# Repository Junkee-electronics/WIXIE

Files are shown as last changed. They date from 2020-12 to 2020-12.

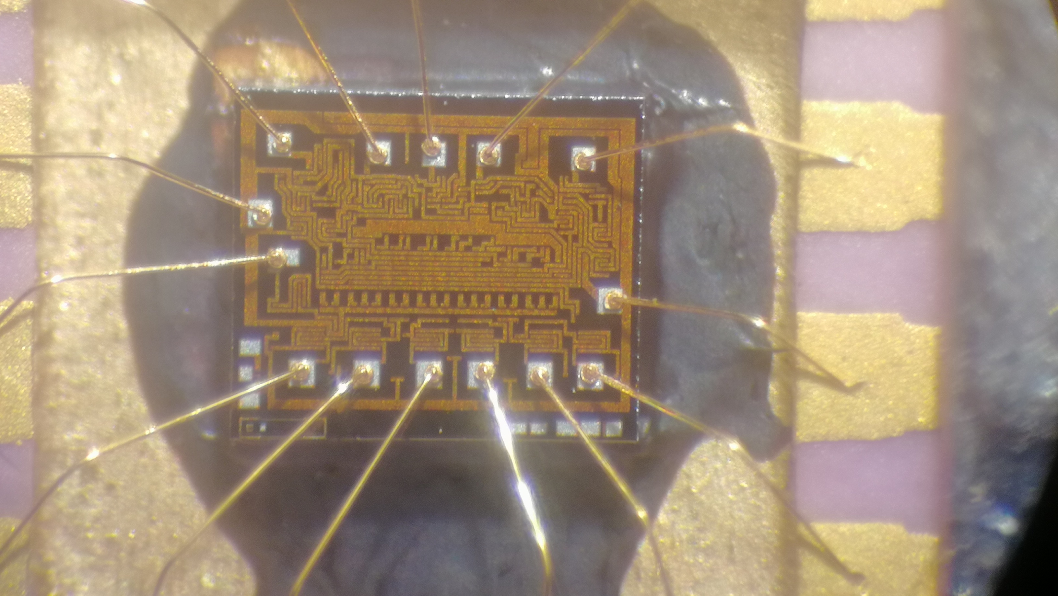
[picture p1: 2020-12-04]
k133ID1.jpg

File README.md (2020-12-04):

# WIXIE

a project for 2 digit nixie watch.
single button operation etc.
synchronised via RTC.
wireless charging.

//No alarms yet! (maybe in the future)
EDIT: ok, i thought about it and i think i implemented it somewhat okay.

possibly will be developing the PCB in the near future.

currently moved to a backburner, as it tested ok, but the driver chip for the nixies is KO.

if anyone is curious, ill upload the supposed k133ID1 delidded picture. by my assumption, its mighty suss.
  -of outer 16 pins, internally bonded only 14.
  -outer VCC pin isn't connected to anything, not even the base platform for the substrate (not even bonded directly to the platform, only glued).
  -lacking amount of output buffer transistors, i count only 7.
well, what could i expect from russians, huh (an attemted joke) :)

STILL DISLIKE LIBRARIES;

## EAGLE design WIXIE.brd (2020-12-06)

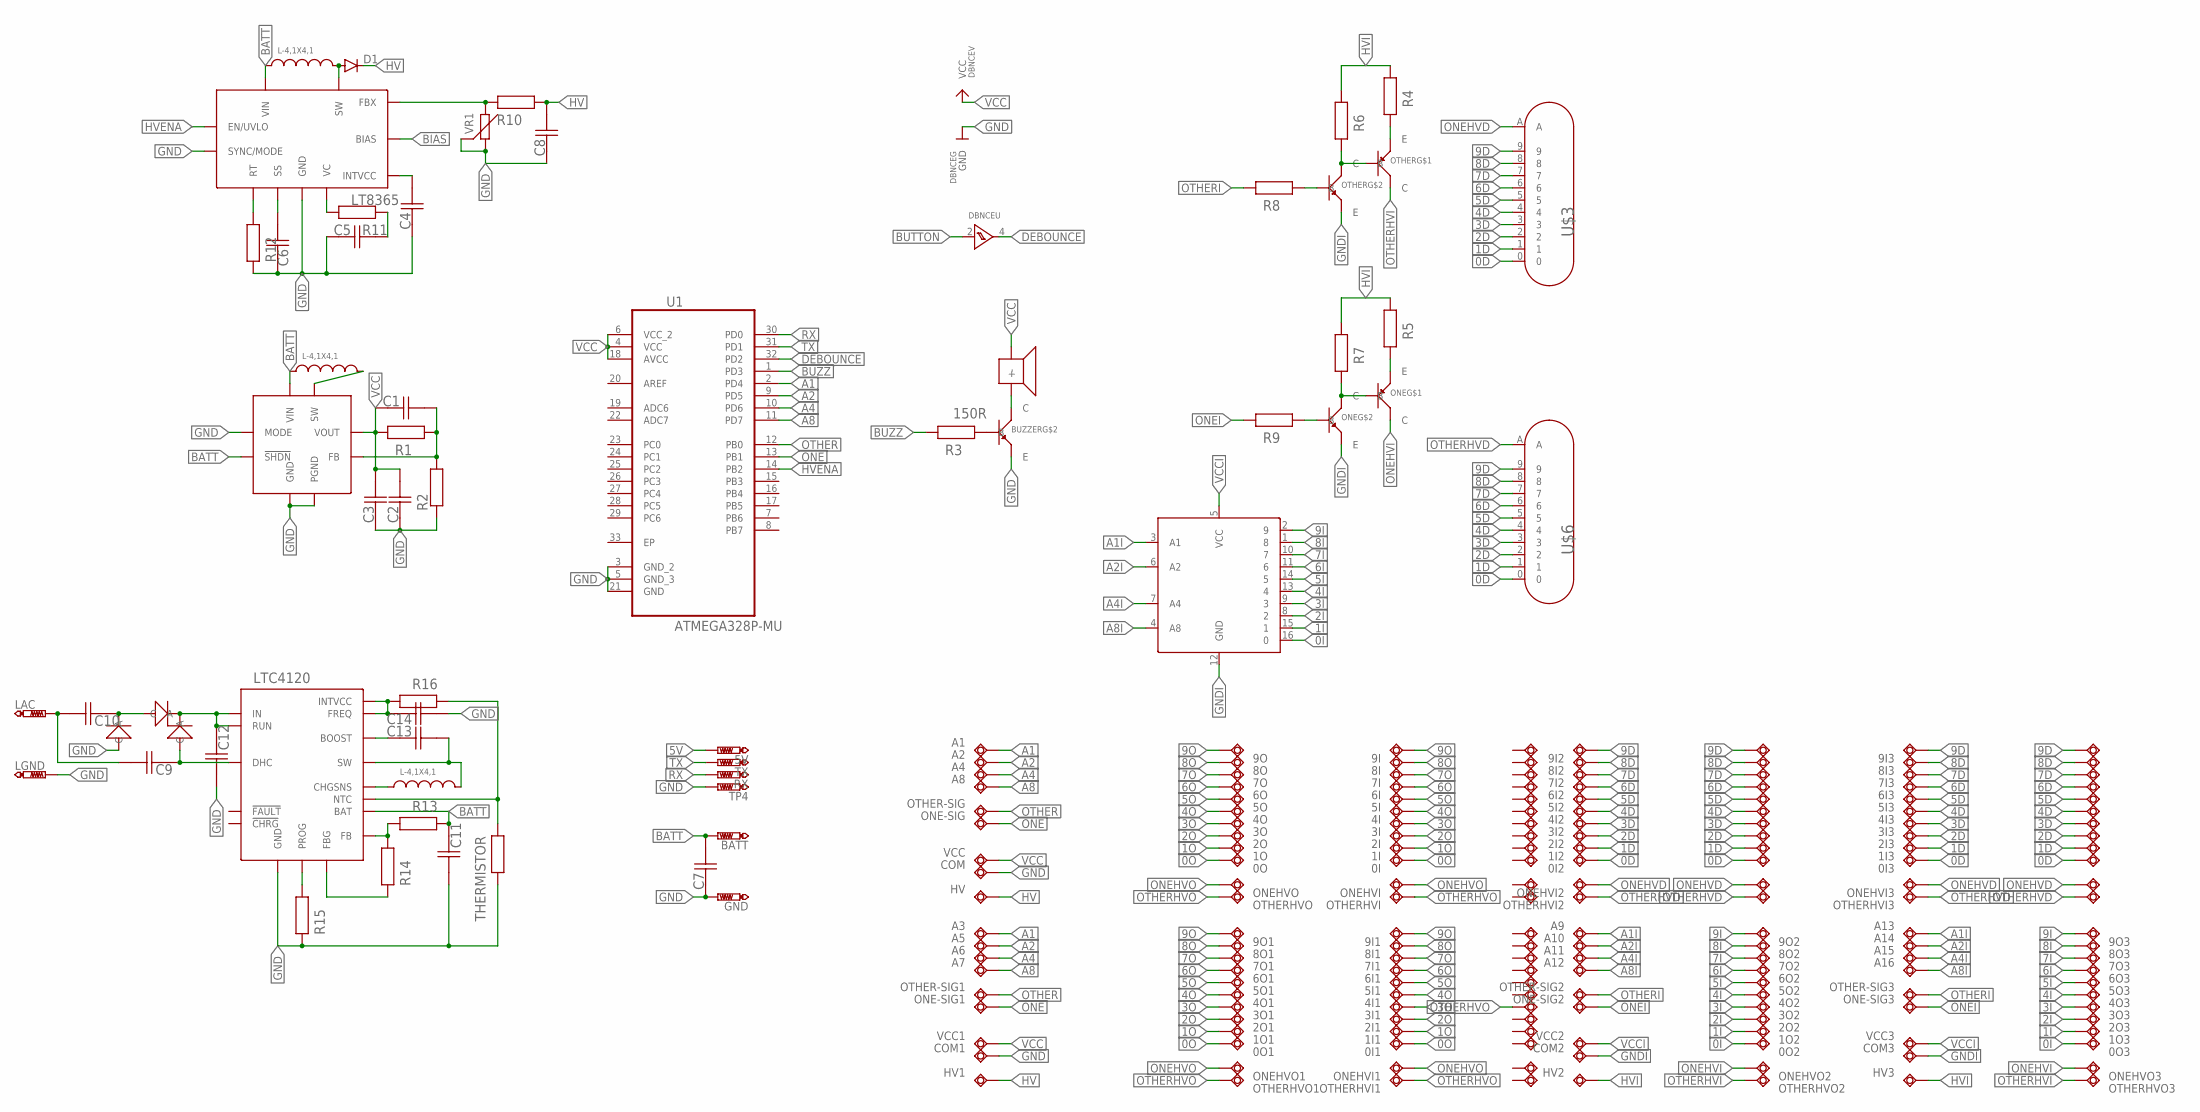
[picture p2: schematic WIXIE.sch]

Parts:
0I, 0I1, 0I2, 0I3, 0O, 0O1, 0O2, 0O3, 1I, 1I1, 1I2, 1I3, 1O, 1O1, 1O2, 1O3, 2I, 2I1, 2I2, 2I3, 2O, 2O1, 2O2, 2O3, 3I, 3I1, 3I2, 3I3, 3O, 3O1, 3O2, 3O3, 4I, 4I1, 4I2, 4I3, 4O, 4O1, 4O2, 4O3, 5I, 5I1, 5I2, 5I3, 5O, 5O1, 5O2, 5O3, 6I, 6I1, 6I2, 6I3, 6O, 6O1, 6O2, 6O3, 7I, 7I1, 7I2, 7I3, 7O, 7O1, 7O2, 7O3, 8I, 8I1, 8I2, 8I3, 8O, 8O1, 8O2, 8O3, 9I, 9I1, 9I2, 9I3, 9O, 9O1, 9O2, 9O3: TPSQTP12SQ; TP12SQ
5V: PTR1B1,27; B1,27
A1, A2, A3, A4, A5, A6, A7, A8, A9, A10, A11, A12, A13, A14, A15, A16: TPSQTP12SQ; TP12SQ
BATT: PTR1PAD1-13; P1-13
BUZZER: MMDT5451; SOT-363
C1, C2, C3, C4, C5, C6, C7, C8, C9, C10, C11, C12, C13, C14: CAPACITOR-0603; 0603
COM, COM1, COM2, COM3: TPSQTP12SQ; TP12SQ
D1: DIODE-SOD123; SOD123
DBNCE: 74AHC1G17; SOT-353-1
GND: PTR1PAD1-13; P1-13
HV, HV1, HV2, HV3: TPSQTP12SQ; TP12SQ
LAC: PTR1PAD1-13; P1-13
LGND: PTR1PAD1-13; P1-13
LT8365: LT8365; MSE16
LTC3539: LTC3539; DFN8-2X3
LTC4120: LTC4120; QFN16
ONE: MMDT5451; SOT-363
ONE-SIG, ONE-SIG1, ONE-SIG2, ONE-SIG3: TPSQTP12SQ; TP12SQ
ONEHVI, ONEHVI1, ONEHVI2, ONEHVI3: TPSQTP12SQ; TP12SQ
ONEHVO, ONEHVO1, ONEHVO2, ONEHVO3: TPSQTP12SQ; TP12SQ
OTHER: MMDT5451; SOT-363
OTHER-SIG, OTHER-SIG1, OTHER-SIG2, OTHER-SIG3: TPSQTP12SQ; TP12SQ
OTHERHVI, OTHERHVI1, OTHERHVI2, OTHERHVI3: TPSQTP12SQ; TP12SQ
OTHERHVO, OTHERHVO1, OTHERHVO2, OTHERHVO3: TPSQTP12SQ; TP12SQ
R1, R2, R4, R5, R6, R7, R8, R9, R10, R11, R12, R13, R14, R15, R16: RESISTOR-0603; 0603
R3: 150R; 0603
RX: PTR1B1,27; B1,27
THERMISTOR: RESISTOR-0603; 0603
TP1, TP2, TP3, TP5, TP6, TP7, TP8, TP9, TP10, TP11, TP12, TP13, TP14, TP15, TP16, TP17, TP18, TP19, TP20, TP21, TP22, TP23, TP24, TP25, TP26, TP27, TP28, TP29, TP30, TP31, TP32, TP33, TP34, TP35, TP36, TP37, TP38, TP39, TP40, TP41, TP42, TP43, TP44, TP45, TP46, TP47, TP48, TP49: TPSQTP12SQ; TP12SQ
TP4: PTR1B1,27; B1,27
TX: PTR1B1,27; B1,27
U1: ATMEGA328P-MU; QFN50P500X500X100-33N
U$2: BUZZ-8.5X8.5
U$3, U$6: IN-17
U$5, U$11, U$12: ZENER0603; 0603DIODE
U$7, U$8, U$10: L-4,1X4,1; L-4.1X4.1
U$9: K133ID1
VCC, VCC1, VCC2, VCC3: TPSQTP12SQ; TP12SQ
VR1: SR3305

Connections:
0D: 0I2.TP, 0I3.TP, TP23.TP, TP47.TP, U$3.0, U$6.0
0I: 0O2.TP, 0O3.TP, U$9.16 (0)
0O: 0I.TP, 0I1.TP, 0O.TP, 0O1.TP
1D: 1I2.TP, 1I3.TP, TP22.TP, TP34.TP, U$3.1, U$6.1
1I: 1O2.TP, 1O3.TP, U$9.15 (1)
1O: 1I.TP, 1I1.TP, 1O.TP, 1O1.TP
2D: 2I2.TP, 2I3.TP, TP21.TP, TP33.TP, U$3.2, U$6.2
2I: 2O2.TP, 2O3.TP, U$9.8 (2)
2O: 2I.TP, 2I1.TP, 2O.TP, 2O1.TP
3D: 3I2.TP, 3I3.TP, TP20.TP, TP32.TP, U$3.3, U$6.3
3I: 3O2.TP, 3O3.TP, U$9.9 (3)
3O: 3I.TP, 3I1.TP, 3O.TP, 3O1.TP
4D: 4I2.TP, 4I3.TP, TP19.TP, TP31.TP, U$3.4, U$6.4
4I: 4O2.TP, 4O3.TP, U$9.13 (4)
4O: 4I.TP, 4I1.TP, 4O.TP, 4O1.TP
5D: 5I2.TP, 5I3.TP, TP18.TP, TP30.TP, U$3.5, U$6.5
5I: 5O2.TP, 5O3.TP, U$9.14 (5)
5O: 5I.TP, 5I1.TP, 5O.TP, 5O1.TP
5V: 5V.TP
6D: 6I2.TP, 6I3.TP, TP17.TP, TP29.TP, U$3.6, U$6.6
6I: 6O2.TP, 6O3.TP, U$9.11 (6)
6O: 6I.TP, 6I1.TP, 6O.TP, 6O1.TP
7D: 7I2.TP, 7I3.TP, TP16.TP, TP28.TP, U$3.7, U$6.7
7I: 7O2.TP, 7O3.TP, U$9.10 (7)
7O: 7I.TP, 7I1.TP, 7O.TP, 7O1.TP
8D: 8I2.TP, 8I3.TP, TP15.TP, TP27.TP, U$3.8, U$6.8
8I: 8O2.TP, 8O3.TP, U$9.1 (8)
8O: 8I.TP, 8I1.TP, 8O.TP, 8O1.TP
9D: 9I2.TP, 9I3.TP, TP14.TP, TP26.TP, U$3.9, U$6.9
9I: 9O2.TP, 9O3.TP, U$9.2 (9)
9O: 9I.TP, 9I1.TP, 9O.TP, 9O1.TP
A1: A1.TP, A3.TP, U1.2 (PD4)
A1I: A9.TP, A13.TP, U$9.3 (A1)
A2: A2.TP, A5.TP, U1.9 (PD5)
A2I: A10.TP, A14.TP, U$9.6 (A2)
A4: A4.TP, A6.TP, U1.10 (PD6)
A4I: A11.TP, A15.TP, U$9.7 (A4)
A8: A7.TP, A8.TP, U1.11 (PD7)
A8I: A12.TP, A16.TP, U$9.4 (A8)
BATT: BATT.TP, C7.2, C11.1, LT8365.3 (VIN), LTC3539.4 (VIN), LTC3539.5 (!SHDN), LTC4120.09 (BAT), R13.1, U$8.P$1, U$10.P$1
BIAS: LT8365.7 (BIAS)
BUTTON: DBNCE.2 (A)
BUZZ: R3.1, U1.1 (PD3)
DEBOUNCE: DBNCE.4 (Y), U1.32 (PD2)
GND: BUZZER.1 (E), C2.1, C3.1, C4.1, C5.1, C6.1, C7.1, C8.1, C11.2, C12.2, C14.2, COM.TP, COM1.TP, DBNCE.3 (GND), GND.TP, LGND.TP, LT8365.12 (SYNC/MODE), LT8365.PAD (GND), LTC3539.2 (PGND), LTC3539.3 (GND), LTC3539.7 (MODE), LTC3539.PAD (GND), LTC4120.05 (GND), R2.1, R12.1, R15.1, THERMISTOR.2, TP4.TP, U1.3 (GND_2), U1.5 (GND_3), U1.21 (GND), U$12.POS (A), VR1.2, VR1.3
GNDI: COM2.TP, COM3.TP, ONE.1 (E), OTHER.1 (E), U$9.12 (GND)
HV: C8.2, D1.C, HV.TP, HV1.TP, R10.2
HVENA: LT8365.1 (EN/UVLO), U1.14 (PB2)
HVI: HV2.TP, HV3.TP, R4.2, R5.2, R6.2, R7.2
N22: C1.2, LTC3539.6 (FB), R1.2, R2.2
unnamed: BUZZER.6 (C), U$2.-
unnamed: LTC3539.1 (SW), U$10.P$2
unnamed: OTHER.4 (E), R4.1
unnamed: BUZZER.2 (B), R3.2
unnamed: C4.2, LT8365.5 (INTVCC)
unnamed: OTHER.5 (B), OTHER.6 (C), R6.1
unnamed: C5.2, R11.2
unnamed: OTHER.2 (B), R8.2
unnamed: D1.A, LT8365.14 (SW), LT8365.16 (SW), U$8.P$2
unnamed: LT8365.9 (FBX), R10.1, VR1.1
unnamed: C10.1, U$5.POS (A), U$12.NEG (C)
unnamed: C9.2, C10.2, LAC.TP
unnamed: LT8365.8 (VC), R11.1
unnamed: C6.2, LT8365.11 (SS)
unnamed: LT8365.10 (RT), R12.2
unnamed: C12.1, LTC4120.03 (IN), LTC4120.16 (RUN), U$5.NEG (C), U$11.NEG (C)
unnamed: C9.1, LTC4120.06 (DHC), U$11.POS (A)
unnamed: LTC4120.13 (PROG), R15.2
unnamed: LTC4120.11 (FBG), R14.1
unnamed: LTC4120.10 (FB), R13.2, R14.2
unnamed: LTC4120.12 (NTC), R16.1, THERMISTOR.1
unnamed: LTC4120.08 (CHGSNS), U$7.P$1
unnamed: C13.2, LTC4120.04 (SW), U$7.P$2
unnamed: C13.1, LTC4120.02 (BOOST)
unnamed: C14.1, LTC4120.01 (INTVCC), LTC4120.07 (FREQ), R16.2
unnamed: ONE.2 (B), R9.2
unnamed: ONE.4 (E), R5.1
unnamed: ONE.5 (B), ONE.6 (C), R7.1
ONE: ONE-SIG.TP, ONE-SIG1.TP, U1.13 (PB1)
ONEHVD: ONEHVI2.TP, ONEHVI3.TP, TP24.TP, TP48.TP, U$3.A
ONEHVI: ONE.3 (C), ONEHVO2.TP, ONEHVO3.TP
ONEHVO: ONEHVI.TP, ONEHVI1.TP, ONEHVO.TP, ONEHVO1.TP
ONEI: ONE-SIG2.TP, ONE-SIG3.TP, R9.1
OTHER: OTHER-SIG.TP, OTHER-SIG1.TP, U1.12 (PB0)
OTHERHVD: OTHERHVI2.TP, OTHERHVI3.TP, TP25.TP, TP49.TP, U$6.A
OTHERHVI: OTHER.3 (C), OTHERHVO2.TP, OTHERHVO3.TP
OTHERHVO: OTHERHVI.TP, OTHERHVI1.TP, OTHERHVO.TP, OTHERHVO1.TP, TP8.TP
OTHERI: OTHER-SIG2.TP, OTHER-SIG3.TP, R8.1
RX: RX.TP, U1.30 (PD0)
TX: TX.TP, U1.31 (PD1)
VCC: C1.1, C2.2, C3.2, DBNCE.5 (VCC), LTC3539.8 (VOUT), R1.1, U1.4 (VCC), U1.6 (VCC_2), U1.18 (AVCC), U$2.+, VCC.TP, VCC1.TP
VCCI: U$9.5 (VCC), VCC2.TP, VCC3.TP

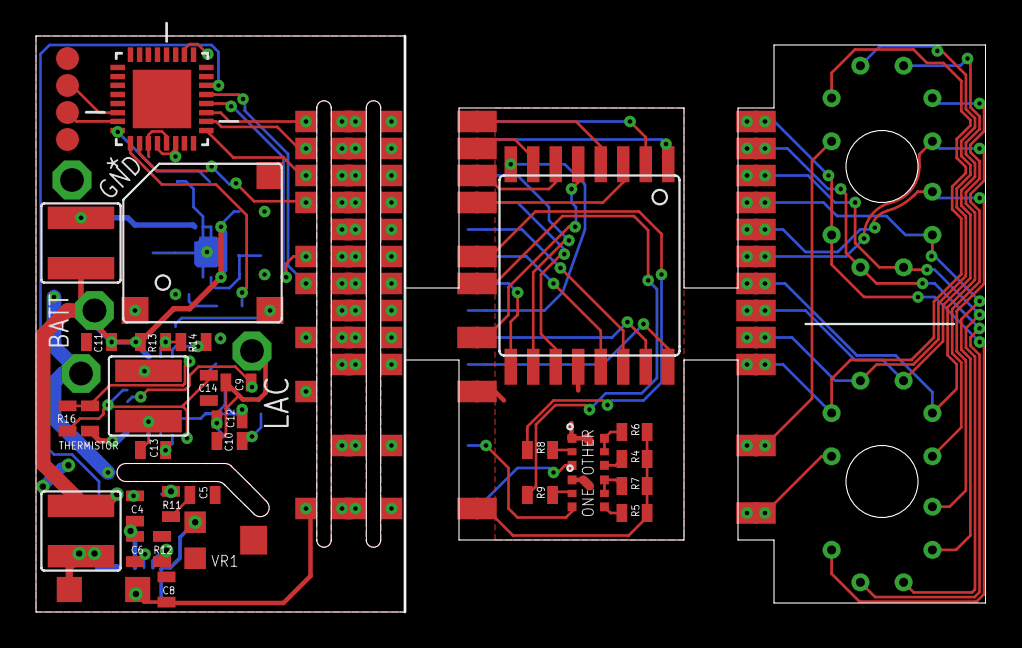
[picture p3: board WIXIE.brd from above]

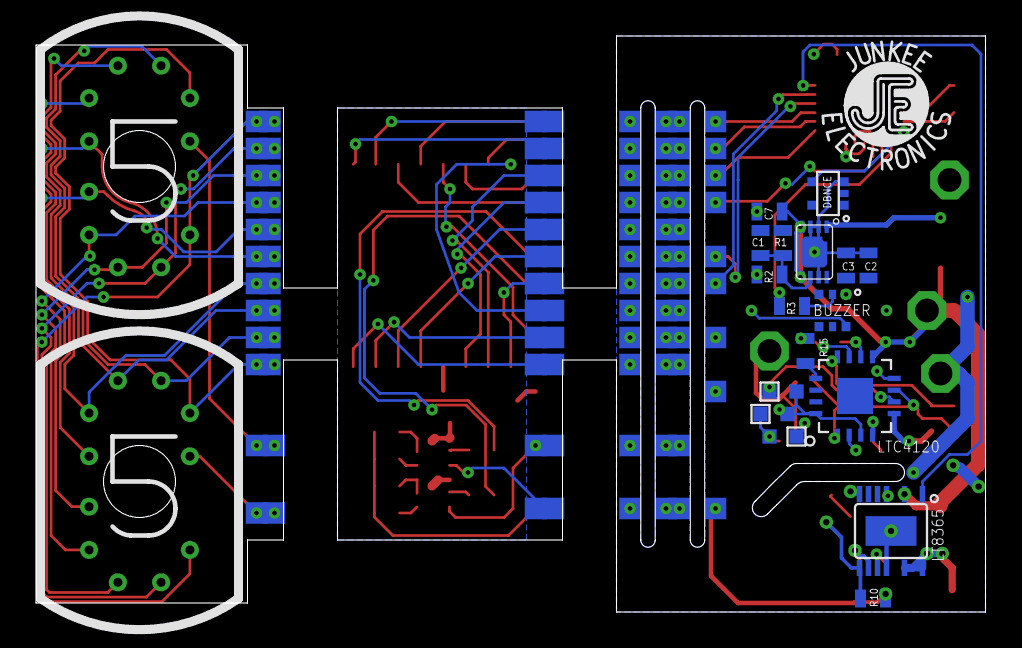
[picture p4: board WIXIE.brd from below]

Board: 2 copper layers, 52.8 x 32.0 mm, 240 parts (113 on the bottom side), 89 nets.

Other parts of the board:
U$1: LOGO

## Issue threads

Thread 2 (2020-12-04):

Dam son, don't waste your resources

Juraell, 2020-12-04:
You can save up some memory by leaving out the debug code by wisely using preprocessor directive:
[Forum thread](https://forum.arduino.cc/index.php?topic=46900.0)

```
#define DEBUG

#ifdef DEBUG
  Serial.print("sec");
  Serial.print(sec);
  Serial.print("min");
  Serial.print(min);
  Serial.print("hr");
  Serial.print(hr);
  Serial.print("day");
  Serial.print(day);
  Serial.print("month");
  Serial.print(month);
  Serial.print("year");
  Serial.print(year);
  Serial.print("hold");
  Serial.print(hold);
  Serial.print("lhold");
  Serial.print(lhold);
  Serial.print("oneother");
  Serial.print(oneother);
  Serial.print("batt");
  Serial.print(batt);
  Serial.print("ena");
  Serial.print(ena);
  Serial.print("call");
  Serial.print(call);
  Serial.print("minor");
  Serial.print(minor);
  Serial.print("major");
  Serial.print(major);
  Serial.print("PORTD");
  Serial.print(PORTD);
  Serial.print("PORTB");
  Serial.print(PORTB);
  Serial.print("set");
  Serial.println(set);
#endif
```

Closed 2020-12-05.

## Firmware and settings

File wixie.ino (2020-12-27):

//#include "RTClib.h"

#define bttn 2
#define A 4
#define B 5
#define C 6
#define D 7
#define one 8
#define other 9
#define buzzer 10
#define battpin A0

//RTC_DS1307 rtc;

uint8_t sec = 30;
uint8_t min = 30;
uint8_t hr = 12;
uint8_t day = 15;
uint8_t month = 6;
uint8_t year = 20;
uint8_t cyclep = 24;
uint8_t repamin = 0;
uint8_t repahr = 0;
uint8_t minor;
uint8_t major;
uint8_t batt;

int unsigned battstate;
int unsigned showtime = 500;

long unsigned trigger;
long unsigned RFRSH = 0;
long unsigned holdtime = 0;
long unsigned repatime;
long unsigned buzz;

bool ena = true;
bool call = true;
bool hold = false;
bool lhold = false;
bool oneother = true;
bool set = false;
bool cycle = false;
bool pm = false;
bool repaena = false;
bool repapm = false;
bool battalarm = false;

// just to do the button checking and crap for enabling all the things that we need for the further functions.
void state() {
    RFRSH = millis();
    holdtime = millis();
    call = true;
    set = true;
}

// mostly setting up I/O and internal timers and

void setup() {

  Serial.begin(9600);

  pinMode(A, OUTPUT);
  pinMode(B, OUTPUT);
  pinMode(C, OUTPUT);
  pinMode(D, OUTPUT);
  pinMode(one, OUTPUT);
  pinMode(other, OUTPUT);
  pinMode(buzzer, OUTPUT);
  pinMode(bttn, INPUT_PULLUP);

  //rtc.begin();

  cli();//stop interrupts

  attachInterrupt(digitalPinToInterrupt(bttn), state, FALLING);

  //set timer0 interrupt at 500Hz
  TCCR0A = 0;// set entire TCCR0A register to 0
  TCCR0B = 0;// same for TCCR0B
  TCNT0  = 0;//initialize counter value to 0
  // set compare match register for 500hz increments
  OCR0A = 124;// = (16*10^6) / (500*64) - 1 (must be <256)
  // turn on CTC mode
  TCCR0A |= (1 << WGM01);
  // Set CS02 bit for 256 prescaler
  TCCR0B |= (1 << CS02);   
  // enable timer compare interrupt
  TIMSK0 |= (1 << OCIE0A);

  //set timer1 interrupt at 1Hz
  TCCR1A = 0;// set entire TCCR1A register to 0
  TCCR1B = 0;// same for TCCR1B
  TCNT1  = 0;//initialize counter value to 0
  // set compare match register for 1hz increments
  OCR1A = 15624;// = (16*10^6) / (1*1024) - 1 (must be <65536)
  // turn on CTC mode
  TCCR1B |= (1 << WGM12);
  // Set CS12 and CS10 bits for 1024 prescaler
  TCCR1B |= (1 << CS12) | (1 << CS10);  
  // enable timer compare interrupt
  TIMSK1 |= (1 << OCIE1A);

  /*
  DateTime now = rtc.now();
  sec = now.second();
  min = now.minute();
  hr = now.hour();
  day = now.day();
  month = now.month();
  year = now.year();
  trigger = millis();
  */

  sei();//allow interrupts
}

//______________________________________________________________________
//timer1 interrupt 1Hz

ISR(TIMER1_COMPA_vect){
  sec++;
}

//______________________________________________________________________
//timer1 interrupt 500Hz,  basically does display multiplexing.

ISR(TIMER0_COMPA_vect){
  if (call){
    if (oneother){
      PORTD &= 0b00001111;
      PORTB &= 0b11000000;
      PORTB |= 0b00000001;
      PORTD = PORTD | minor;
      oneother = false;
    }
    else{
      PORTD &= 0b00001111;
      PORTB &= 0b11000000;
      PORTB |= 0b00000010;
      PORTD = PORTD | major;
      oneother = true;
    }
  }
  else {
     PORTD &= 0b00001111;
     PORTB &= 0b11000000;
  }
}

//______________________________________________________________________

void loop() {
//safety for if millis eventually overflows, the time will stay updated from the RTC in 10 hour intervals.
  if (millis() < trigger) trigger = millis();

/*
  if ((millis() - trigger) > 36000000){
    DateTime now = rtc.now();
    sec = now.second();
    min = now.minute();
    hr = now.hour();
    day = now.day();
    month = now.month();
    year = (now.year())-2000;
    trigger = millis();
  }
*/

// debuging shit, to be left out in the final version, for now, the program only takes like 3600 btes, so no sweat for now
/*
  Serial.print("sec");
  Serial.print(sec);
  Serial.print("min");
  Serial.print(min);
  Serial.print("hr");
  Serial.print(hr);
  Serial.print("day");
  Serial.print(day);
  Serial.print("month");
  Serial.print(month);
  Serial.print("year");
  Serial.print(year);
  Serial.print("hold");
  Serial.print(hold);
  Serial.print("lhold");
  Serial.print(lhold);
  Serial.print("oneother");
  Serial.print(oneother);
  Serial.print("batt");
  Serial.print(batt);
  Serial.print("ena");
  Serial.print(ena);
  Serial.print("call");
  Serial.print(call);
  Serial.print("minor");
  Serial.print(minor);
  Serial.print("major");
  Serial.print(major);
  Serial.print("PORTD");
  Serial.print(PORTD);
  Serial.print("PORTB");
  Serial.print(PORTB);
  Serial.print("set");
  Serial.println(set);
*/

  holder();
  
  //had to add some conditions to make sure it isn't triggered while the button is still pressed.
  if (hold && digitalRead(bttn)){
    convert(batt);
    while ((millis() - RFRSH) < showtime){
      call = true;  
    }
    call = false
  }
  
  //here i dont care about the concept of time anymore. nothing matters anymore. there are just settings. so many settings...
  if (lhold){
    RFRSH = millis();
    showtime /= 10;
    for (uint8_t i = 0; i < 10; i++){
      while ((millis() - RFRSH)<=5000){
        switch (i){
          case 0:
            TIMSK1 &= (0 << OCIE1A);
            adjuster(sec);
            convert(sec);
          break;
          case 1:
            TIMSK1 |= (1 << OCIE1A);
            adjuster(min);
            convert(min);
          break;
          case 2:
            adjuster(hr);
            convert(hr);
          break;
          case 3:
            adjuster(day);
            convert(day);
          break;
          case 4:
            adjuster(month);
            convert(month);
          break;
          case 5:
            adjuster(year);
            convert(year);
          break;
          //this grade A bullshit is just because of 12/24 hr cycle
          case 6:
            if (set){
              cycle != cycle;
              set = false;
            }
            if (cycle) cyclep = 12;
            else cyclep = 24;
          convert(cyclep);
          break;
          //this is for adjustin display on time for each digit
          case 7:
            adjuster(showtime);
            convert(showtime);
          break;
          //setting for repetitive alarm.
          case 8:
            adjuster(repamin);
            convert(repamin);
          break;
          case 9:
            adjuster(repahr);
            if (repahr >= 12) repapm !=;
            else repapm !=;
            convert(repahr);
          break;
          case 10:
            if (set){
              repaena != repaena;
              set = false;
            }            
            convert(repaena);
          break;
          }
        manager();
        }
      }
    showtime *= 10;
    //rtc.adjust(DateTime((year + 2000), month, day, hr, min, sec));
  }

  alarm();

  //reads the battery, converts the range 3v - 4.25v to value 0 - 99, and does a check of whether the battery isnt too far discharged (at 0 [3v])
  battstate =  analogRead(battpin);
  batt = (int) ((((battstate * 5) / 1023)-3) * 80);
  if (batt > 99) batt = 99;
  if (batt > 0) ena = true;
  else ena = false;

  if ((batt == 0) && ((battalarm - millis()) > 3600000)){
    goto loudbeep;
  }

  // displays each thingy-o after set time. dependent on ok state of the battery. preety modular if you want to add some more.
  if (ena && call && !hold){
    manager();
    if ((millis() - RFRSH)<showtime) convert(sec);
    if ((showtime*10)<=(millis() - RFRSH)<(showtime*20)) convert(min);
    if ((showtime*20)<=(millis() - RFRSH)<(showtime*30)) convert(hr);
    if ((showtime*30)<=(millis() - RFRSH)<(showtime*40)) convert(day);
    if ((showtime*40)<=(millis() - RFRSH)<(showtime*50)) convert(month);
    if ((showtime*50)<=(millis() - RFRSH)<(showtime*60)) convert(year);
  }
  else call = false;
}

//determines a long button press or even longer button press
void holder(){
  if ((500 <= (millis() - holdtime) <= 2000) && !digitalRead(bttn)){
    hold = true;
    lhold = false;
  }
  else if (((millis() - holdtime) > 2000) && !digitalRead(bttn)){
    hold = false;
    lhold = true;
  }
  else {
    hold = false;
    lhold = false;
  }
}

// separation of digit one and two, bitshifting them to the left. now take it back now ya'll
void convert(uint8_t vale){
  minor = (vale % 10) << 4;
  major = ((int) vale / 10) << 4;
}

// do some computing for time management, like 60 secs in minute, 60 of them in hour, 12/24 hr. cycle etc.
void manager(){  

  if (showtime >= 80){
    showtime = 80;
  }

  if (sec >= 60){
    sec = 0;
    min++;
  }
  
  if (min >= 60){
    min = 0;
    hr++;
  }
  
  if (cycle){
    if ((hr >= 12)){
      hr = 0;
      pm != pm;
      if (pm) day++;
    }
  }
  else {
    if ((hr >= 24)){
      hr = 0;
      day++;
    }
  }

  if (repamin >= 60){
    repamin = 0;
  }    

  if ((repahr >= 24)){
    repahr = 0;
  }

  switch (month){
    
  //31 days months
      case 1:
      case 3:
      case 5:
      case 7:
      case 8:
      case 10:
        if (day >= 32){   //Make sure you don't overflow accidentally
          day= 1;
          month++;
        }
      break;

  //30 days months
      case 4:
      case 6:
      case 9:
      case 11:
        if (day >= 31){
          day= 1;
          month++;
        }
      break;

  //December - EOY (end of the year)
      case 12:
        if (day >= 32){
          day = 1;
          month = 1;
          year++;
        }
      break;

  //And last but not least - Mr. weird one - February
    case 2:
      if ((year % 4) == 0){
        if (day >= 30){
          day= 1;
          month++;
        }
      }
      else{
        if (day >= 29){
          day= 1;
          month++;
        }
      }
    break;
  }
  year %= 100;
}

// manages procedural addition to a numerical value dependant on button press. doesn't work on bool values, or values not specified in manager().
// good idea to call manager afterwards, to make sure you dont overflow or display a nonsensical value :)
void adjuster(uint8_t val){
  holder();
  if (set){
    val++;
    set = false;
  }
  if (hold || lhold)RFRSH = millis() - 5000;
}

// just checks if sethr == hr etc, and does some shit in case of 12HR mode is active (i hate 12HR mode :\)
void alarm(){
  if (repaena){
    if ((hr == repahr) && ((pm && repapm) || (!pm && !repapm))){
      if (min == repamin){
        loudbeep:
        repatime = millis();
        TIMSK0 &= (0 << OCIE0A);
        // holds the program still while its in alarm active state, to exit, do anything with the button or wait like 2 minutes or smthng
        while (((millis() - repatime) < 120000) || !ena){
          if (millis() < buzz){
            repatime = millis();
            buzz = millis();
            //makes sure the time doesnt go of the rails even while the alarm is active
            manager();
          }
          //fix if millis() overflows in the middle of the loop. yes the 2 min. timer for auto-alarm-dissable doesnt exactly line up, but whatevs :D
          if ((millis() - buzz) >= 1000){
            tone(buzzer, 120, 500);
            buzz = millis();
          }
        }
        //this is done in case the tone() which uses internal interrupts chooses timer 0, which it will do, because i deactivated it just prior to the while().
        //or maybe it wont since the mode is still set to CTC, IDK, i have came across this for the first time, better safe than be left with a stuck wristwatch.
        TCCR0A = 0;// set entire TCCR0A register to 0
        TCCR0B = 0;// same for TCCR0B
        TCNT0  = 0;//initialize counter value to 0
        OCR0A = 124;// = (16*10^6) / (500*64) - 1 (must be <256)
        TCCR0A |= (1 << WGM01);
        TCCR0B |= (1 << CS02);   
        TIMSK0 |= (1 << OCIE0A);
        battalarm = millis();
      }
    }
  }
}
